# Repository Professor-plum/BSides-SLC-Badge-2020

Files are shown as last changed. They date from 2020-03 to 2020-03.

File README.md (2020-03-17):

# BSides-SLC-Badge-2020
Source code, design files, artwork, resoources and 3D printer models used in the BSides SLC 2020 badge

Hardware schematics were design using Eagle
Firmware was compiled using STM32CubeIDE

Programming was done using a ST-link v2 and a USB-TTY tool.# BSides-SLC-Badge-2020
Source code, design files, artwork, resoources and 3D printer models used in the BSides SLC 2020 badge

Hardware schematics were design using Eagle
Firmware was compiled using STM32CubeIDE
All artwork is in the images folder
There are a few scripts inside the resources folder which were used to compile the flash image and program the badges

Programming was done using a ST-link v2 and a USB-TTY tool.

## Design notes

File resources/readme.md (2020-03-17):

# CASE FILE:	Pulverized Power

March 20, 2020

A local power company has been experiencing multiple cases of equipment malfunction and suspects sabotage.

## Background

Charles Puckett, regional manager at Tri-City Power has requested that I look into a string of broken substation circuit breakers. My instinct tells me something fishy is going on here and these outages aren't a mere coincidence. I need to interview the local employees and gather evidence if I'm to confirm this hunch. 

All evidence I collect will be stored with on this disk.

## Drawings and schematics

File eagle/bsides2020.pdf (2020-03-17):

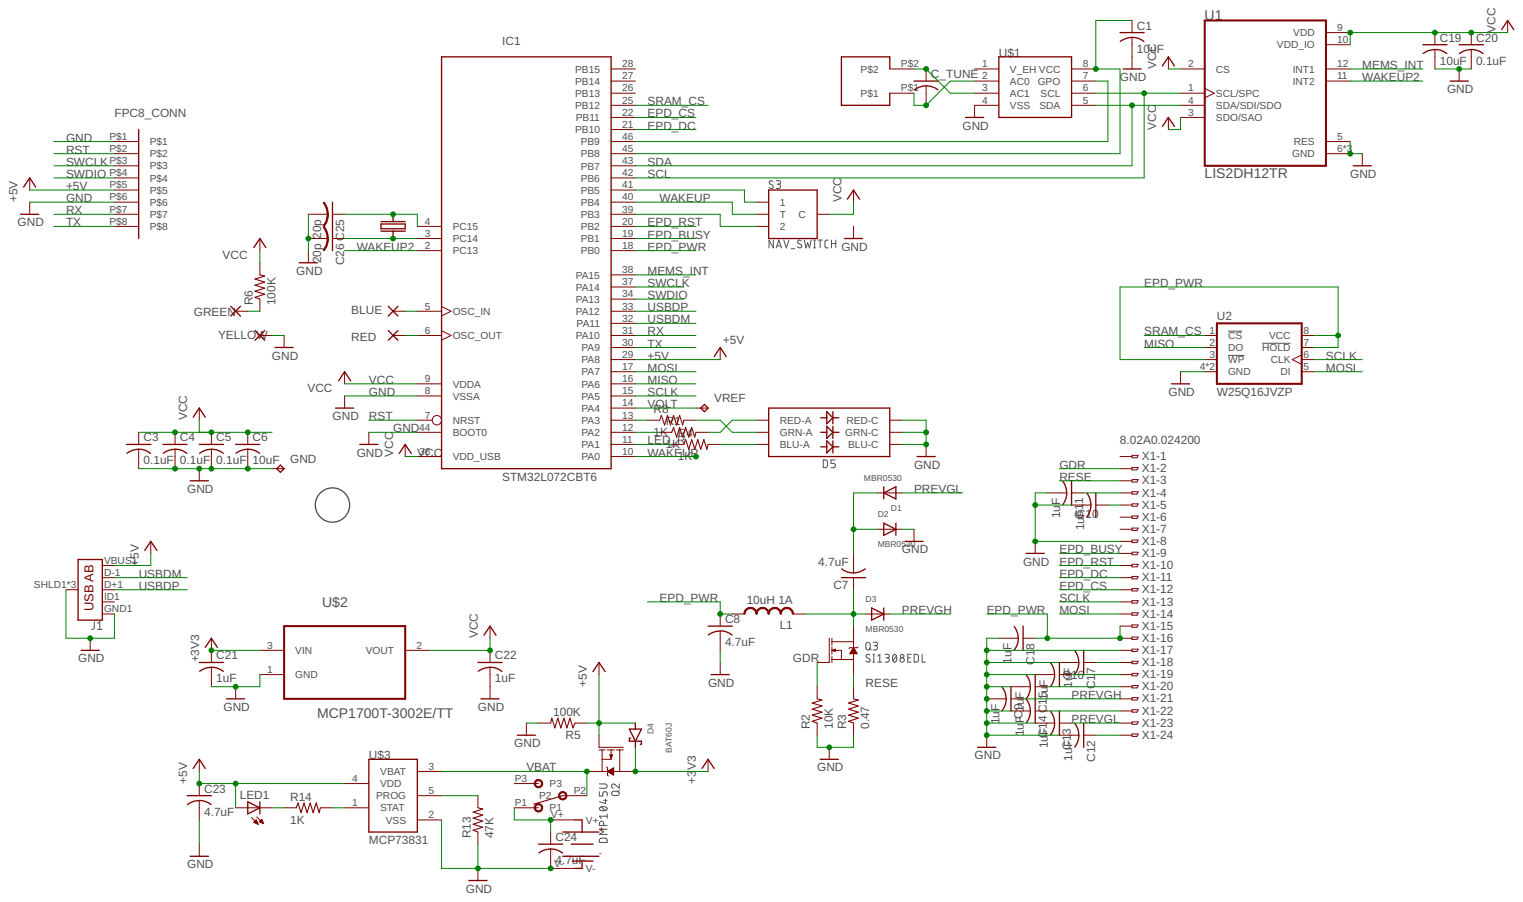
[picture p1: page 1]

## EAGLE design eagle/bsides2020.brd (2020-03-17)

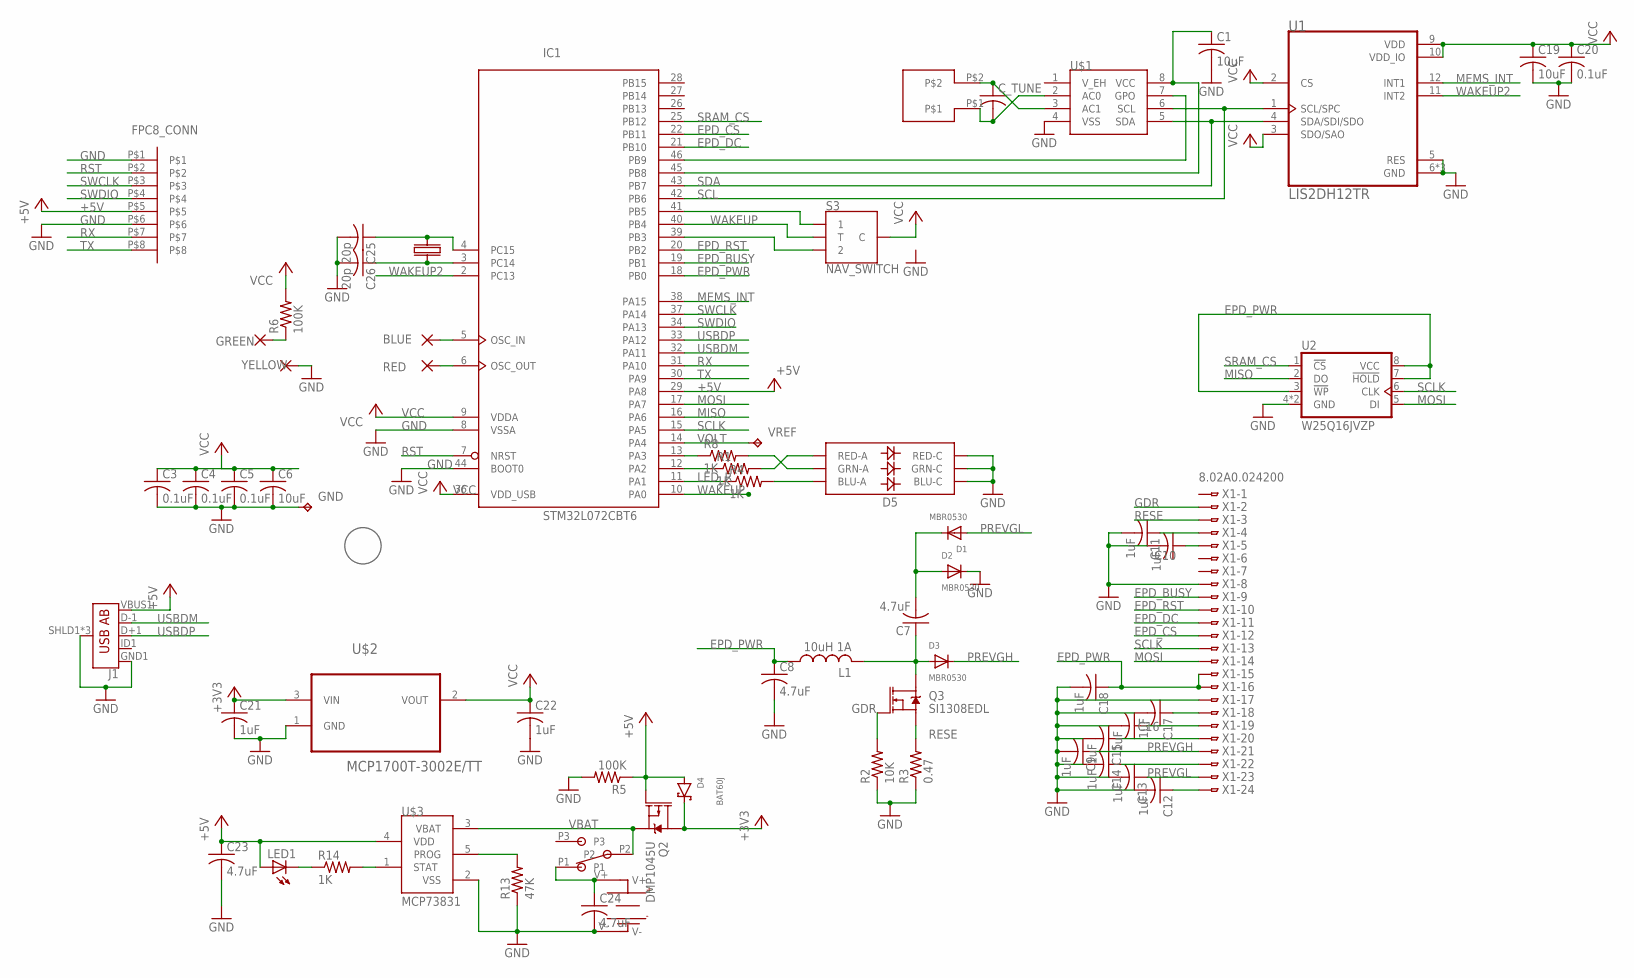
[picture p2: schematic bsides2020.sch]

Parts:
BLUE: SMD2; SMD1,27-2,54
C1, C6, C19: 10uF; C0603
C3, C4, C5, C20: 0.1uF; C0603
C7, C8, C23, C24: 4.7uF; C0603
C9, C10, C11, C12, C13, C14, C15, C16, C17, C18, C21, C22: 1uF; C0603
C25, C26: 20p; C0603
C_TUNE: C-USC0603; C0603
D1, D2, D3: MBR0530; SOD-123
D4: BAT60J; SOD323_ST
D5: RGB; LED-TRICOLOR-5050
GND: TPB1,27; B1,27
GREEN: SMD2; SMD1,27-2,54
IC1: STM32L072CBT6; LQFP48
J1: USB_AB_SMT; USB-AB-MICRO-SMD
L1: 10uH 1A; L2825P
LED1: LEDCHIPLED_0603; CHIPLED_0603
Q2: DMP1045U; SOT23-3
Q3: SI1308EDL; SOT23-3
R1, R4, R8, R14: 1K; R0603
R2: 10K; R0603
R3: 0.47; R0603
R5, R6: 100K; R0603
R13: 47K; R0603
RED: SMD2; SMD1,27-2,54
S3: NAV_SWITCH
U1: LIS2DH12TR; LGA-12N
U2: W25Q16JVZP; WSON8
U$1: ST25DV04K-IER6S3; SOIC127P600X175-8N
U$2: MCP1700T-3002E/TT; SOT95P237X112-3N
U$3: MCP73831; SOT23-5L
U$4: ANTANT2; ANT2
U$6: 20MM_BATTERY180; 20MM_BATTERY_SMD2
U$7: FPC8_END
U$8: PLUM
U$9: MSK12C02
U$11: MC-306 32.7680K-A0:ROHS; 32KHZCRYSTAL
VREF: TPB1,27; B1,27
X1: 8.02A0.024200; FPC24
YELLOW: SMD2; SMD1,27-2,54

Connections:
+3V3: C21.1, D4.C, Q2.3 (D), U$2.3 (VIN)
+5V: C23.1, D4.A, IC1.29 (PA8), J1.VBUS1 (VBUS), LED1.A, Q2.1 (G), R5.1, U$3.4 (VDD), U$7.P$5
EPD_BUSY: IC1.19 (PB1), X1.P$9
EPD_CS: IC1.22 (PB11), X1.P$12
EPD_DC: IC1.21 (PB10), X1.P$11
EPD_PWR: C8.1, C18.1, IC1.18 (PB0), L1.1, U2.3 (!WP!), U2.7 (!HOLD!), U2.8 (VCC), X1.P$15, X1.P$16
EPD_RST: IC1.20 (PB2), X1.P$10
GDR: Q3.1 (G), R2.2, X1.P$2
GND: C1.2, C3.2, C4.2, C5.2, C6.2, C8.2, C9.2, C10.2, C11.2, C12.2, C13.2, C14.2, C15.2, C16.2, C17.2, C18.2, C19.2, C20.2, C21.2, C22.2, C23.2, C24.2, C25.2, C26.2, D2.C, D5.4 (BLU-C), D5.5 (RED-C), D5.6 (GRN-C), GND.TP, IC1.8 (VSSA), IC1.23 (VSS), IC1.35 (VSS), IC1.44 (BOOT0), IC1.47 (VSS), J1.GND1 (GND), J1.SHLD1 (SHIELD), J1.SHLD2 (SHIELD), J1.SHLD3 (SHIELD), R2.1, R3.1, R5.2, R13.1, U1.5 (RES), U1.6 (GND), U1.7 (GND), U1.8 (GND), U2.4 (GND), U2.9 (GND), U$1.4 (VSS), U$2.1 (GND), U$3.2 (VSS), U$6.V-, U$7.P$1, U$7.P$6, X1.P$8, X1.P$17, YELLOW.1
LED_R: IC1.11 (PA1), R4.1
MEMS_INT: IC1.38 (PA15), U1.12 (INT1)
MISO: IC1.16 (PA6), U2.2 (DO)
MOSI: IC1.17 (PA7), U2.5 (DI), X1.P$14
unnamed: R13.2, U$3.5 (PROG)
unnamed: BLUE.1, IC1.5 (OSC_IN)
unnamed: D5.2 (RED-A), R1.2
unnamed: D5.1 (GRN-A), R8.2
unnamed: D5.3 (BLU-A), R4.2
unnamed: IC1.41 (PB5), S3.1
unnamed: C24.1, U$6.V+, U$9.P1
unnamed: C26.1, IC1.3 (PC14), U$11.P$4
unnamed: IC1.46 (PB9), U$1.7 (GPO)
unnamed: C_TUNE.2, U$1.2 (AC0), U$4.P$1
unnamed: C11.1, X1.P$4
unnamed: IC1.39 (PB3), S3.2
unnamed: IC1.12 (PA2), R1.1
unnamed: IC1.13 (PA3), R8.1
unnamed: C25.1, IC1.4 (PC15), U$11.P$1
unnamed: C7.1, D3.A, L1.2, Q3.3 (D)
unnamed: C10.1, X1.P$5
unnamed: IC1.6 (OSC_OUT), RED.1
unnamed: C1.1, IC1.45 (PB8), U$1.8 (VCC)
unnamed: C16.1, X1.P$19
unnamed: C15.1, X1.P$20
unnamed: C17.1, X1.P$18
unnamed: C14.1, X1.P$22
unnamed: C12.1, X1.P$24
unnamed: GREEN.1, R6.1
unnamed: C7.2, D1.C, D2.A
unnamed: C_TUNE.1, U$1.3 (AC1), U$4.P$2
unnamed: LED1.C, R14.1
unnamed: R14.2, U$3.1 (STAT)
PREVGH: C9.1, D3.C, X1.P$21
PREVGL: C13.1, D1.A, X1.P$23
RESE: Q3.2 (S), R3.2, X1.P$3
RST: IC1.7 (NRST), U$7.P$2
RX: IC1.31 (PA10), U$7.P$7
SCL: IC1.42 (PB6), U1.1 (SCL/SPC), U$1.6 (SCL)
SCLK: IC1.15 (PA5), U2.6 (CLK), X1.P$13
SDA: IC1.43 (PB7), U1.4 (SDA/SDI/SDO), U$1.5 (SDA)
SRAM_CS: IC1.25 (PB12), U2.1 (!CS!)
SWCLK: IC1.37 (PA14), U$7.P$3
SWDIO: IC1.34 (PA13), U$7.P$4
TX: IC1.30 (PA9), U$7.P$8
USBDM: IC1.32 (PA11), J1.D-1 (D-)
USBDP: IC1.33 (PA12), J1.D+1 (D+)
VBAT: Q2.2 (S), U$3.3 (VBAT), U$9.P2
VCC: C3.1, C4.1, C5.1, C6.1, C19.1, C20.1, C22.1, IC1.1 (VDD), IC1.9 (VDDA), IC1.24 (VDD), IC1.36 (VDD_USB), IC1.48 (VDD), R6.2, S3.C, U1.2 (CS), U1.3 (SDO/SAO), U1.9 (VDD), U1.10 (VDD_IO), U$2.2 (VOUT)
VOLT: IC1.14 (PA4), VREF.TP
WAKEUP: IC1.10 (PA0), IC1.40 (PB4), S3.T
WAKEUP2: IC1.2 (PC13), U1.11 (INT2)

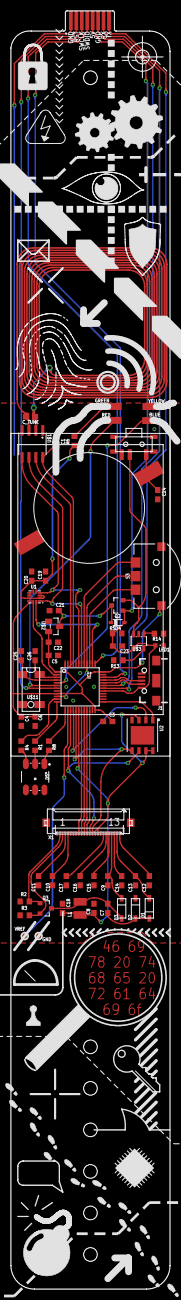
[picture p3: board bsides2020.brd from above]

Board: 2 copper layers, 29.2 x 234.5 mm, 66 parts (0 on the bottom side), 61 nets.

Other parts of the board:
U$5: EPD_2.13

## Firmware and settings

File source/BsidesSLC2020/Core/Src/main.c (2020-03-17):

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

/* Includes ------------------------------------------------------------------*/
#include "main.h"
#include "usb_device.h"

/* USER CODE BEGIN Includes */
#include "mems.h"
#include "epd.h"
#include "w25qxx.h"
#include "lib_NDEF_Text.h"
#include "nfc.h"
#include "game.h"
#include "eeprom.h"
#include "usbd_comp_if.h"
#include "flags.h"
/* USER CODE END Includes */

/* USER CODE BEGIN PTD */
/*const uint8_t ledWav[] = {
		0x2,0xa,0x15,0x25,0x39,0x4f,0x67,0x80,0x98,0xb0,0xc6,0xda,0xea,0xf5,0xfd,0xff,0xfd,0xf5,0xea,0xda,0xc6,0xb0,0x98,0x80,0x67,0x4f,0x39,0x25,0x15,0xa,0x2,0x0,
		0,0,0,0,0,0,0,0,0,0,0,0,0,0,0,0,0,0,0,0,0,0,0,0,0,0,0,0,0,0,0,0,
		};*/
/* USER CODE END PTD */

ADC_HandleTypeDef hadc;

DAC_HandleTypeDef hdac;

RTC_HandleTypeDef hrtc;

SPI_HandleTypeDef hspi1;

TIM_HandleTypeDef htim21;

UART_HandleTypeDef huart1;

/* USER CODE BEGIN PV */
uint16_t idle=0;
uint32_t tick=0;
uint8_t	led_show=0;
uint8_t led_idx=0;
uint8_t stay_awake=0;
uint32_t debounce=0;
uint8_t last_event=EVENT_NONE;
uint8_t uartbyte;
enum UsartState ustate = IDLE;

/**
  * @brief  Retargets the C library printf function to the USART.
  * @param  None
  * @retval None
  */
PUTCHAR_PROTOTYPE
{
  /* Place your implementation of fputc here */
  /* e.g. write a character to the EVAL_COM1 and Loop until the end of transmission */
  HAL_UART_Transmit(&huart1, (uint8_t *)&ch, 1, 0xFFFF);

  return ch;
}
/* USER CODE END PV */

void SystemClock_Config(void);
static void MX_GPIO_Init(void);
static void MX_DAC_Init(void);
static void MX_SPI1_Init(void);
static void MX_USART1_UART_Init(void);
static void MX_TIM21_Init(void);
static void MX_ADC_Init(void);
static void MX_RTC_Init(void);
/* USER CODE BEGIN PFP */
//static void ledColor(uint8_t r, uint8_t g, uint8_t b);
static void setLED(bool r, bool g, bool b);
static void SystemPower_Config(void);
static void Sleep(void);
static void Standby(void);
static void ProgramFlash(void);
/* USER CODE END PFP */

/**
  * @brief  The application entry point.
  * @retval int
  */
int main(void)
{
  

  /* MCU Configuration--------------------------------------------------------*/

  /* Reset of all peripherals, Initializes the Flash interface and the Systick. */
  HAL_Init();

  /* Configure the system clock */
  SystemClock_Config();

  /* Initialize all configured peripherals */
  MX_GPIO_Init();
  MX_DAC_Init();
  MX_SPI1_Init();
  MX_USART1_UART_Init();
  MX_USB_DEVICE_Init();
  MX_TIM21_Init();
  MX_ADC_Init();
  MX_RTC_Init();
  /* USER CODE BEGIN 2 */
  //ledColor(0, 0, 255);
  SystemPower_Config();
  if (!MEMS_Init()){
	  puts("Mems Init failed!");
	  Error_Handler();
  }
  if (!NFC_Init()) {
	  puts("NFC Init failed!");
	  Error_Handler();
  }

  if (!W25qxx_Init()) {
	  puts("Flash Init failed!");
	  Error_Handler();
  }

  /*hrng.Instance = RNG;
  if (HAL_RNG_Init(&hrng) != HAL_OK)
  {
	  Error_Handler();
  }*/

  GameInit();
  MX_USB_DEVICE_Init();

  uint8_t resume = __HAL_PWR_GET_FLAG(PWR_FLAG_SB) != RESET;
  if (resume) {

      /* Clear Standby flag */
      __HAL_PWR_CLEAR_FLAG(PWR_FLAG_SB);

      //setLED(false, true, false);

      //ADC Must be enabled to set the calibration value
      __HAL_ADC_ENABLE(&hadc);
      uint32_t adc_cal = HAL_RTCEx_BKUPRead(&hrtc, ADC_CAL_REG);
      HAL_ADCEx_Calibration_SetValue(&hadc, ADC_SINGLE_ENDED, adc_cal);

      if (__HAL_RTC_WAKEUPTIMER_GET_FLAG(&hrtc, RTC_FLAG_WUTF) == SET) {
		  puts("RTC Wakeup");
		  Standby();
		  //We don't return from this
	  }

	  puts("Event Wakeup");

      //We woke up from a key press so pass that on to the game
      last_event = EVENT_KEY_SELECT;
  }
  else{
	  puts("Init");
	  //TODO: run a systems check (Validate Flash data)

	  HAL_ADCEx_Calibration_Start(&hadc,ADC_SINGLE_ENDED);
	  uint32_t adc_cal = HAL_ADCEx_Calibration_GetValue(&hadc, ADC_SINGLE_ENDED);
	  HAL_RTCEx_BKUPWrite(&hrtc, ADC_CAL_REG, adc_cal);

	  DrawLogo(true);
  }

  uint16_t bat = readVoltage();
  printf("Battery is at %d.%dV\n", bat/1000, bat%1000);

  HAL_TIM_Base_Start_IT(&htim21);
  //HAL_TIM_Base_Start_IT(&htim2);

  //HAL_DMA_Start(&hdma_tim6_up, (uint32_t)&ledPins,  (uint32_t)&GPIOC->ODR, 16);
  // _HAL_TIM_ENABLE_DMA(&htim6, TIM_DMA_UPDATE);
  // __HAL_TIM_ENABLE(&htim6);

  /* USER CODE END 2 */

  /* Infinite loop */
  /* USER CODE BEGIN WHILE */
  if (HAL_GPIO_ReadPin(VBUS_GPIO_Port, VBUS_Pin) == GPIO_PIN_SET)
  	  stay_awake |= USB_POWER;
  while (1)
  {
	  if (last_event != EVENT_NONE) {
		  uint8_t evt = last_event;
		  if (evt == EVENT_NFC) {
			  while (last_event != EVENT_NONE) {
				  last_event= EVENT_NONE;
				  HAL_Delay(100); // just to let the NFC write actually finish
			  }
		  }
		  last_event= EVENT_NONE;
		  GameEvent(evt);
	  }

	  if (ustate == WIPE_PENDING) {
		  puts("Erasing flash memory");
		  W25qxx_EraseChip();
		  puts("Erase complete");
		  ustate = IDLE;
	  }
	  else if (ustate == SYSTEM_TEST) {
		  //TODO: system test
		  puts("OK - system test complete");
		  ustate = IDLE;
	  }
	  else if (ustate == PROGRAM) {
		  stay_awake=1;
		  ProgramFlash();
		  ustate = IDLE;
	  }
	  CDC_Process();
	  GameTick();
    /* USER CODE END WHILE */

    /* USER CODE BEGIN 3 */
	  if (stay_awake==0)
  	  	  Sleep();
	  else
		  HAL_Delay(10);
  }
  /* USER CODE END 3 */
}

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
/* USER CODE BEGIN 4 */
void setLED(bool r, bool g, bool b) {
	HAL_GPIO_WritePin(GPIOA, RED_LED_Pin, g?GPIO_PIN_SET:GPIO_PIN_RESET);
	HAL_GPIO_WritePin(GPIOA, GRN_LED_Pin, r?GPIO_PIN_SET:GPIO_PIN_RESET);
	HAL_GPIO_WritePin(GPIOA, BLU_LED_Pin, b?GPIO_PIN_SET:GPIO_PIN_RESET);
}

void notifyLED(bool r, bool g, bool b) {
	led_show=3;
	setLED(r, g, b);
}
/*void ledColor(uint8_t r, uint8_t g, uint8_t b) {
    TIM_OC_InitTypeDef sConfigOC;

    sConfigOC.OCMode = TIM_OCMODE_PWM1;
    sConfigOC.OCPolarity = TIM_OCPOLARITY_HIGH;
    sConfigOC.OCFastMode = TIM_OCFAST_DISABLE;
    sConfigOC.Pulse = b;
    HAL_TIM_PWM_ConfigChannel(&htim2, &sConfigOC, TIM_CHANNEL_2);
    sConfigOC.Pulse = r;
    HAL_TIM_PWM_ConfigChannel(&htim2, &sConfigOC, TIM_CHANNEL_3);
    sConfigOC.Pulse = g;
    HAL_TIM_PWM_ConfigChannel(&htim2, &sConfigOC, TIM_CHANNEL_4);
    HAL_TIM_PWM_Start(&htim2, TIM_CHANNEL_2);
    HAL_TIM_PWM_Start(&htim2, TIM_CHANNEL_3);
    HAL_TIM_PWM_Start(&htim2, TIM_CHANNEL_4);
}*/

void HAL_GPIO_EXTI_Callback( uint16_t GPIO_Pin) {
	uint8_t s;
	uint32_t now = tick;
	//printf("EXTI %x at %d\n", GPIO_Pin, now);
	switch (GPIO_Pin) {
	case GPIO_PIN_13:
		puts("Motion event?");
		break;
	case MEMS_INT_Pin:
		s = MEMS_Process();
		if (s==1){
			last_event = EVENT_DOUBLE_TAP;
			led_show=3;
			//setLED(true, false, true);
		}
		else if (s==2) {
			last_event = EVENT_HIT;
			led_show=3;
			//setLED(false, false, true);
		}
		else
			return; //don't count this a activity and don't keep system awake
	case VBUS_Pin:
		if (HAL_GPIO_ReadPin(VBUS_GPIO_Port, VBUS_Pin) == GPIO_PIN_SET) {
			stay_awake |= USB_POWER;
			puts("USB power on");
		}
		else {
			stay_awake &= ~USB_POWER;
			puts("%d USB power off");
		}
		break;
	case NFC_INT_Pin:
		puts("NFC event");
		last_event = EVENT_NFC;
		break;
	case BTN_DN_Pin:
		if ((now - debounce) > DEBOUNCE) {
			puts("button down");
			last_event = EVENT_KEY_DOWN;
			debounce = now;
		}
		break;
	case BTN_UP_Pin:
		if ((now - debounce) > DEBOUNCE) {
			puts("button up");
			last_event = EVENT_KEY_UP;
			debounce = now;
		}
		break;
	case BTN_Pin:
		if ((now - debounce) > DEBOUNCE) {
			puts("button enter");
			last_event = EVENT_KEY_SELECT;
			debounce = now;
		}
		break;
	case GPIO_PIN_1:
		if ((now - debounce) > DEBOUNCE) {
			puts("pad jumped");
			last_event = EVENT_WIRE_JUMP;
			debounce = now;
		}
		break;
	default:
		printf("%d Unknown EXTI event via pin %x\n", now, GPIO_Pin);
		break;
	}

	idle=0;
	HAL_PWR_DisableSleepOnExit();
}

void HAL_TIM_PeriodElapsedCallback(TIM_HandleTypeDef *htim)
{
	if (htim->Instance == htim21.Instance){
		int s = tick++ %50;
		if (led_show)
			led_show--;
		else if (s < 7) {
			if (s % 2)
				setLED(false, false, false);
			else
				switch(GetLandmarks().group[s/2]) {
				case 0:
					setLED(true, false, false);
					break;
				case 1:
					setLED(true, true, true);
					break;
				case 2:
					setLED(false, true, false);
					break;
				case 3:
					setLED(false, true, true);
					break;
				case 4:
					setLED(false, false, true);
					break;
				}
		}
		else
			setLED(false, false, false);
		/*if (HAL_GPIO_ReadPin(GPIOC, GPIO_PIN_13) == GPIO_PIN_SET) {
			idle=0;
		}*/
		idle++;

		if ((idle>=WAKETIME)) {// && (ledWav[led_idx % 64] == 0))
			if (stay_awake == 0){
				printf("Idle for %ds, ", idle/5);
				Standby();
			}
			//else if (idle == WAKETIME)
			//	DrawLogo(true);
		}

		//if (HAL_GPIO_ReadPin(GPIOH, GPIO_PIN_1) == GPIO_PIN_RESET)
		//	puts("jumped");
	}
}

/* This callback is called by the HAL_UART_IRQHandler when the given number of bytes are received */
void HAL_UART_RxCpltCallback(UART_HandleTypeDef *huart)
{
  if (huart->Instance == USART1)
  {
	  if (ustate==IDLE) {
		  switch(uartbyte) {
		  case 'w':
		  case 'W':
			  setWritable(1);
			  puts("Flash writing enabled");
			  break;
		  case 'l':
		  case 'L':
			  setWritable(0);
			  puts("Flash writing disabled");
			  break;
		  case 'r':
		  case 'R':
			  puts("Reboot initiated");
			  NVIC_SystemReset();
			  break;
		  case 'e':
		  case 'E':
			  puts("Are you sure you want to erase all flash memory!?");
			  ustate = WIPE_CONFIRM;
			  break;
		  case 'g':
		  case 'G':
			  puts("Are you sure you want reset game progress!?");
			  ustate = RESET_CONFIRM;
			  break;
		  case 'p':
		  case 'P':
			  puts("Preparing to program flash via terminal ");
			  ustate = PROGRAM;
			  return;
		  case 'f':
		  case 'F':
			  printf("Game flags: %s\n", GameFlags());
			  break;
		  default:
			  puts("Welcome to Plum's service terminal");
			  puts("\tR - Reboots badge");
			  puts("\tG - Resets game progress");
			  puts("\tT - Runs systems test");
			  puts("\tE - Erases all content on the NOR FLash");
			  puts("\tW - Enables writing to the NOR flash via USB(must be erased first)");
			  puts("\tL - Disables writing to the flash via USB");
			  puts("\tP - Program flash over terminal");
			  puts("\tF - Show game flags state");

		  }
	  }
	  else if (ustate==WIPE_CONFIRM) {
		  if ((uartbyte == 'y') || (uartbyte == 'Y')) {
			  ustate = WIPE_PENDING;
			  HAL_PWR_DisableSleepOnExit();
		  }
		  else {
			  puts("Erase canceled");
			  ustate = IDLE;
		  }
	  }
	  else if (ustate==RESET_CONFIRM) {
		  if ((uartbyte == 'y') || (uartbyte == 'Y')) {
			  puts("Game progress reset");
			  GameReset();
		  }
		  else
			  puts("Reset canceled");
		  ustate = IDLE;
	  }
	  else if (ustate==WIPE_PENDING)
		  puts("Please wait, NOR flash is being erased");
	  else if (ustate==SYSTEM_TEST)
		  puts("System test in progress");
	/* Receive one byte in interrupt mode */
	HAL_UART_Receive_IT(&huart1, &uartbyte, 1);
  }
}

static void ProgramFlash(void) {
	uint8_t buf[256];
	uint32_t expected;
	W25qxx_EraseChip();
	puts("Ready, enter Flash size:");

	HAL_UART_Receive(&huart1, &expected, sizeof(expected), HAL_MAX_DELAY);
	expected /= w25qxx.PageSize;
	printf("Writing %d pages\n", expected);

	for (uint32_t addr=0; addr<expected; ++addr) {
		HAL_UART_Receive(&huart1, buf, 256, HAL_MAX_DELAY);
		W25qxx_WritePage(buf, addr, 0, w25qxx.PageSize);
		puts(".");
	}

	puts("done");
	//restore normal behavior
	HAL_UART_Receive_IT(&huart1, &uartbyte, 1);
}

static void SystemPower_Config(void)
{
  /* Enable Ultra low power mode */
  HAL_PWREx_EnableUltraLowPower();

  /* Enable the fast wake up from Ultra low power mode */
  HAL_PWREx_EnableFastWakeUp();
}

void Sleep() {
	puts("sleeping");

    /* Configure low-power mode */
    //SCB->SCR &= ~( SCB_SCR_SLEEPDEEP_Msk );  // low-power mode = sleep mode
    //SCB->SCR |= SCB_SCR_SLEEPONEXIT_Msk;     // reenter low-power mode after ISR

    /* Ensure Flash memory stays on */
    //FLASH->ACR &= ~FLASH_ACR_SLEEP_PD;
    //__WFI();  // enter low-power mode

	HAL_PWR_EnableSleepOnExit();
	HAL_SuspendTick();
    HAL_PWR_EnterSLEEPMode(PWR_MAINREGULATOR_ON, PWR_SLEEPENTRY_WFI);
    HAL_ResumeTick();
    puts("awake");
}

void Standby() {
	puts("Going to standby");
	HAL_NVIC_DisableIRQ(EXTI2_3_IRQn);
	HAL_NVIC_DisableIRQ(EXTI4_15_IRQn);

	//setLED(false, false, true);
	NFC_PowerDown();
	//ledColor(0,0,0);


	HAL_ResumeTick();

	GamePause();
	if (readVoltage() < 3100)
		EPD_DrawLowPower(80, 196);
	W25qxx_PowerDown();
	HAL_Delay(75);

	HAL_GPIO_WritePin(EPD_PWR_GPIO_Port, EPD_PWR_Pin, GPIO_PIN_RESET); //Turn off EPD
	//HAL_DeInit();

	MEMS_Clear(); //Clear any missed motion events

	HAL_SuspendTick();
	setLED(false, false, false);

	HAL_RTCEx_DeactivateWakeUpTimer(&hrtc);
	//TODO: set this to seconds left before next minute +1
	HAL_RTCEx_SetWakeUpTimer_IT(&hrtc, 59, RTC_WAKEUPCLOCK_CK_SPRE_16BITS);

	HAL_PWR_DisableWakeUpPin(PWR_WAKEUP_PIN1);
	HAL_PWR_DisableWakeUpPin(PWR_WAKEUP_PIN2);
	/* Clear all related wakeup flags*/
	__HAL_PWR_CLEAR_FLAG(PWR_FLAG_WU);
	/* Enable WakeUp Pin PWR_WAKEUP_PIN1 connected to PA.0 */
	HAL_PWR_EnableWakeUpPin(PWR_WAKEUP_PIN1);  //Select Key press
	//HAL_PWR_EnableWakeUpPin(PWR_WAKEUP_PIN2);  //Movement

	HAL_PWR_EnterSTANDBYMode();
}



uint16_t readVoltage() {

	//Wait until ADC is fully powered up, probably not necessary
	while(!__HAL_PWR_GET_FLAG(PWR_FLAG_VREFINTRDY));

	HAL_ADC_Start(&hadc);
	HAL_ADC_PollForConversion(&hadc, 1000);

	uint32_t volt_count = HAL_ADC_GetValue(&hadc);

	uint16_t voltage = (3000 * (*VREFINT_CAL_ADDR))/volt_count;
	HAL_ADC_Stop(&hadc);

	return voltage;
}

int dayofweek(int d, int m, int y)
{
    static int t[] = { 0, 3, 2, 5, 0, 3, 5, 1, 4, 6, 2, 4 };
    y -= m < 3;
    int r= ( y + y/4 - y/100 + y/400 + t[m-1] + d) % 7;
    if (r==0) r=7;
    return r;
}

bool SetTime(char* line) {
	unsigned int mon,day,year,hour,min,sec;
	RTC_TimeTypeDef sTime = {0};
	RTC_DateTypeDef sDate = {0};

	// "MM/DD/YY HH:MM:SS"
	int c = sscanf(line, "%2u/%2u/%2u %2u:%2u:%2u",&mon,&day,&year,&hour,&min,&sec);
	if (c!=6)
		return false;

	sTime.Hours = hour;
	sTime.Minutes = min;
	sTime.Seconds = sec;
	sTime.DayLightSaving = RTC_DAYLIGHTSAVING_NONE;
	sTime.StoreOperation = RTC_STOREOPERATION_RESET;

	sDate.WeekDay = dayofweek(day, mon, year);
	sDate.Month = mon;
	sDate.Date = day;
	sDate.Year = year;

	HAL_RTC_SetTime(&hrtc, &sTime, RTC_FORMAT_BIN);
	HAL_RTC_SetDate(&hrtc, &sDate, RTC_FORMAT_BIN);
	return true;
}

/* USER CODE END 4 */
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


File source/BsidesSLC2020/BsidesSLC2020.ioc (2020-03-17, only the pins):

PH0-OSC_IN.Signal=GPIO_Input
Mcu.UserName=STM32L072CBTx
PB0.GPIO_Label=EPD_PWR
PB11.Signal=GPIO_Output
PA15.GPIO_Label=MEMS_INT
PA12.Signal=USB_DP
PB6.Signal=I2C1_SCL
PH0-OSC_IN.GPIO_Label=BLUE
PB2.Signal=GPIO_Output
PB12.GPIO_Label=FLASH_CS
PB1.GPIO_Label=EPD_BUSY
PB7.Signal=I2C1_SDA
PA8.Signal=GPXTI8
PA0.Signal=SYS_WKUP1
PB9.Signal=GPXTI9
PB1.Signal=GPIO_Input
PA6.Signal=SPI1_MISO
PA2.GPIO_Label=GRN_LED
PA10.Signal=USART1_RX
PA15.Signal=GPXTI15
PB5.GPIO_Label=BTN_UP
PB4.Signal=GPXTI4
PA3.Signal=GPIO_Output
PB3.GPIO_Label=BTN_DN
PB9.GPIO_Label=NFC_INT
PC13.Signal=SYS_WKUP2
PB11.GPIO_Label=EPD_CS
PC14-OSC32_IN.Signal=RCC_OSC32_IN
PA13.Signal=SYS_SWDIO
PB8.GPIO_Label=NFC_PWR
PA8.GPIO_Label=VBUS
PB10.GPIO_Label=EPD_DC
PA9.Signal=USART1_TX
PC15-OSC32_OUT.Signal=RCC_OSC32_OUT
PA1.Signal=GPIO_Output
PB10.Signal=GPIO_Output
PA5.Signal=SPI1_SCK
PB4.GPIO_Label=BTN
PA1.GPIO_Label=RED_LED
PH1-OSC_OUT.Signal=GPIO_Input
PH1-OSC_OUT.GPIO_Label=RED
PA2.Signal=GPIO_Output
PB3.Signal=GPXTI3
PA4.Signal=COMP_DAC1_group
PB5.Signal=GPXTI5
PA11.Signal=USB_DM
PA14.Signal=SYS_SWCLK
PB2.GPIO_Label=EPD_RST
PB8.Signal=GPIO_Output
PB0.Signal=GPIO_Output
PB12.Signal=GPIO_Output
PA3.GPIO_Label=BLU_LED
PA7.Signal=SPI1_MOSI

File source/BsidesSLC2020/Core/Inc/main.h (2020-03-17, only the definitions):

#define WAKETIME	100
#define USB_POWER	1
#define USART_OPEN	2
#define DEBOUNCE	2
#define VREFINT_CAL_ADDR ((uint16_t*) ((uint32_t) 0x1FF80078))
#define COMMAND_MAX_LENGTH 16
#define PUTCHAR_PROTOTYPE int __io_putchar(int ch)
#define PUTCHAR_PROTOTYPE int fputc(int ch, FILE *f)
#define BLUE_Pin GPIO_PIN_0
#define BLUE_GPIO_Port GPIOH
#define RED_Pin GPIO_PIN_1
#define RED_GPIO_Port GPIOH
#define RED_LED_Pin GPIO_PIN_1
#define RED_LED_GPIO_Port GPIOA
#define GRN_LED_Pin GPIO_PIN_2
#define GRN_LED_GPIO_Port GPIOA
#define BLU_LED_Pin GPIO_PIN_3
#define BLU_LED_GPIO_Port GPIOA
#define EPD_PWR_Pin GPIO_PIN_0
#define EPD_PWR_GPIO_Port GPIOB
#define EPD_BUSY_Pin GPIO_PIN_1
#define EPD_BUSY_GPIO_Port GPIOB
#define EPD_RST_Pin GPIO_PIN_2
#define EPD_RST_GPIO_Port GPIOB
#define EPD_DC_Pin GPIO_PIN_10
#define EPD_DC_GPIO_Port GPIOB
#define EPD_CS_Pin GPIO_PIN_11
#define EPD_CS_GPIO_Port GPIOB
#define FLASH_CS_Pin GPIO_PIN_12
#define FLASH_CS_GPIO_Port GPIOB
#define VBUS_Pin GPIO_PIN_8
#define VBUS_GPIO_Port GPIOA
#define VBUS_EXTI_IRQn EXTI4_15_IRQn
#define MEMS_INT_Pin GPIO_PIN_15
#define MEMS_INT_GPIO_Port GPIOA
#define MEMS_INT_EXTI_IRQn EXTI4_15_IRQn
#define BTN_DN_Pin GPIO_PIN_3
#define BTN_DN_GPIO_Port GPIOB
#define BTN_DN_EXTI_IRQn EXTI2_3_IRQn
#define BTN_Pin GPIO_PIN_4
#define BTN_GPIO_Port GPIOB
#define BTN_EXTI_IRQn EXTI4_15_IRQn
#define BTN_UP_Pin GPIO_PIN_5
#define BTN_UP_GPIO_Port GPIOB
#define BTN_UP_EXTI_IRQn EXTI4_15_IRQn
#define NFC_PWR_Pin GPIO_PIN_8
#define NFC_PWR_GPIO_Port GPIOB
#define NFC_INT_Pin GPIO_PIN_9
#define NFC_INT_GPIO_Port GPIOB
#define NFC_INT_EXTI_IRQn EXTI4_15_IRQn

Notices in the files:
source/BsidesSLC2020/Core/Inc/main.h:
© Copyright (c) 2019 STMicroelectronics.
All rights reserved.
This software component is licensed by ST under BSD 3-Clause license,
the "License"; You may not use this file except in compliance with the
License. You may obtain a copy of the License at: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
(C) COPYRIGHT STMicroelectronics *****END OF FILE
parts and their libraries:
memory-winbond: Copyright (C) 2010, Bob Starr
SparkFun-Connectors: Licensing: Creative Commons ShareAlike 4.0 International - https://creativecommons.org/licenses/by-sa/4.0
